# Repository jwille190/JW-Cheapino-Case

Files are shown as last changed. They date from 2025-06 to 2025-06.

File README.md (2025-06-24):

# JW-Cheapino-Case
Files for the Cheapino v2 case I designed.

__Please note that the RJ45 connector I used is 11.5mm tall.__ For the controller cover to fit, you will need that same low profile RJ45 connector.

# BOM

Printed Pieces

| Qty | Part |
| --- | --- |
|  1  | L Case body |
|  1  | R Case body (mirror in slicer) |
|  1  | L Switchplate |
|  1  | R Switchplate (mirror in slicer) |
|  1  | L Controller Cover |
|  1  | R Controller Cover (mirror in slicer)  |
|  2  | Pivot hubs |
|  2  | Magnet Circles |
|  2  | Tenting Ramps |

Hardware

| Qty  | Part |
| ---- | --- |
|  16  | M2 Heatset inserts* |
|  16  | M2 x 8mm Socket head cap screws |
| 2  | M4 Heatset inserts* |
| 2  | M4 x 10mm pan-head machine screw |
|  18  | D4x2 Round Magnet (N50M Grade from Bambu Lab Maker's Supply or similar)  |

*You can find heat set insert kits that have multiple sizes, like these. https://www.amazon.com/Threaded-Inserts-Plastic-knurled-Assortment/dp/B0DCJ4MXCM

You will need a tool to install them.

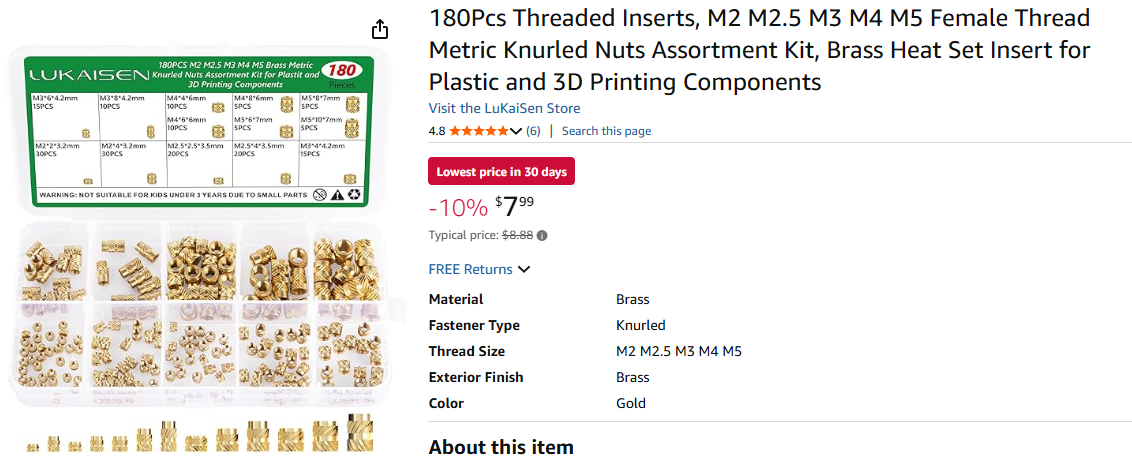
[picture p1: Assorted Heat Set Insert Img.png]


# CRITICAL ASSEMBLY NOTES:
The controller cover is specifically designed for the shorter RJ45 connector that is 11.5mm tall, check the height before assembly.
https://www.amazon.com/uxcell-Unshielded-Modular-Network-Connectors/dp/B007POCUF2
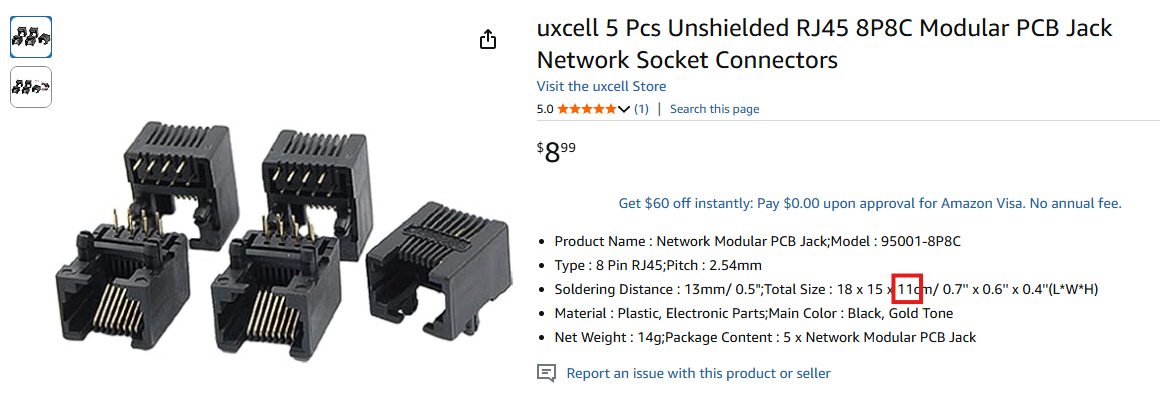
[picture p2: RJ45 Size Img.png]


It also requires short headers equal to the ones in the Adafruit short headers kit for their Feather board.
https://www.adafruit.com/product/2940f

You will need to put the controller cover in place before attaching the populated switchplate to the PCB. The cover does not have a fastener to lock it in place, just the switchplate.
Check that the USB-C connector is seated in the cutout.

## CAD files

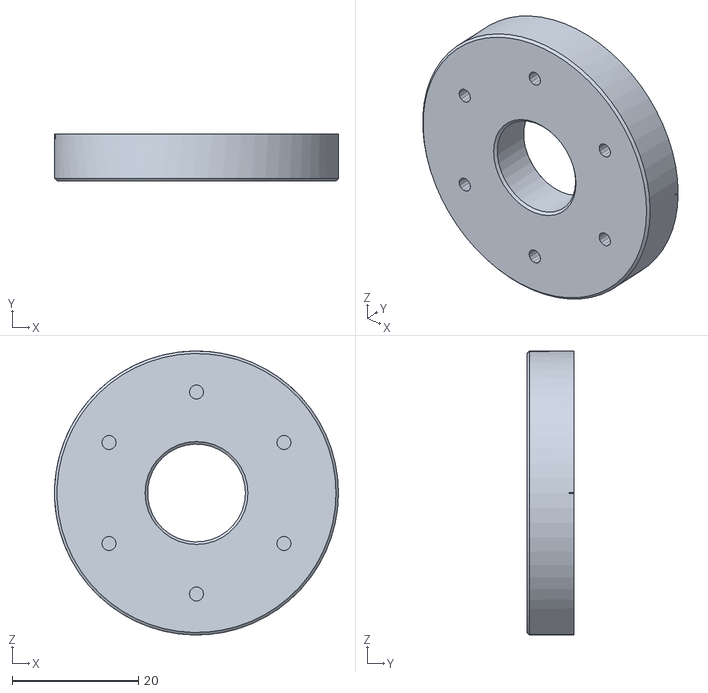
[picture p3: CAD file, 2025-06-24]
Case Ramp Magnet Circle.stl
45.0 x 7.50 x 45.0

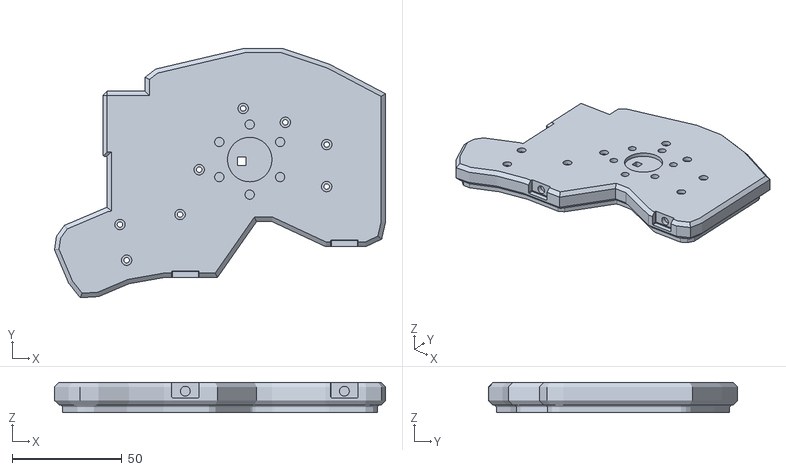
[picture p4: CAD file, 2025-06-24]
Chp_v2 Case.stl
150.9 x 113.7 x 13.8

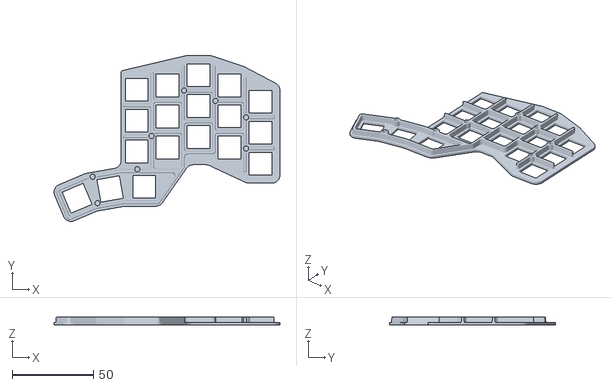
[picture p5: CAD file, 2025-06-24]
Chp_v2 Switchplate.stl
138.8 x 101.8 x 5.10

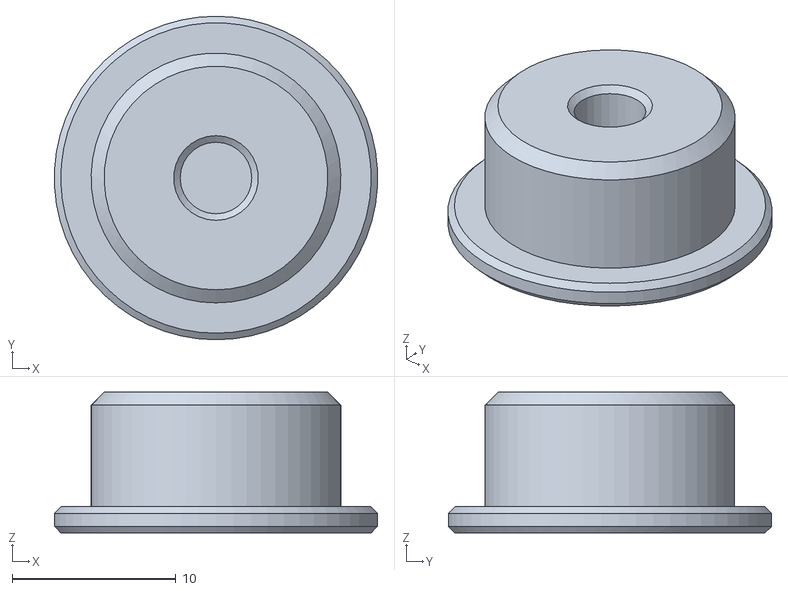
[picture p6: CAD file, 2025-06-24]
Case Ramp Pivot Hub.stl
19.7 x 19.8 x 8.60

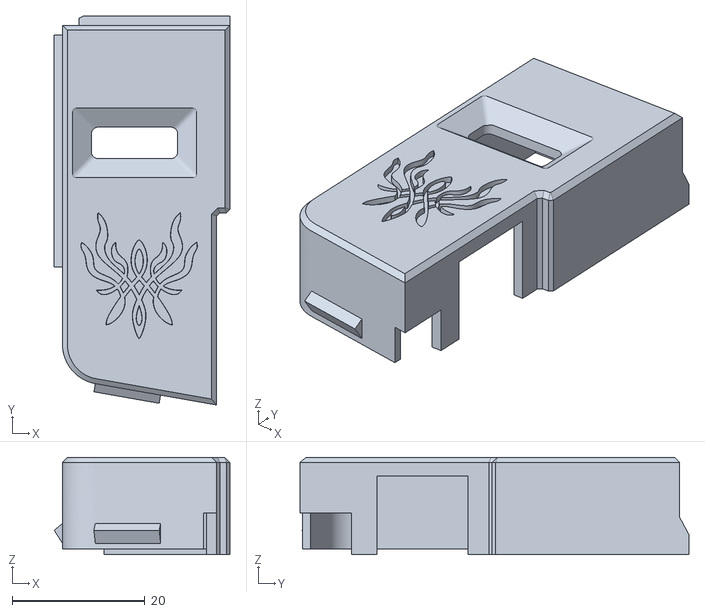
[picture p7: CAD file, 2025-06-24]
Chp_v2 Controller Cover (Crest of Flames Logo).stl
26.5 x 58.7 x 14.6

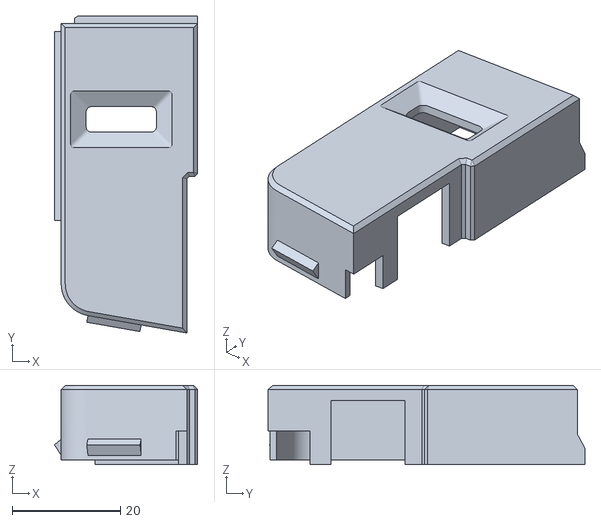
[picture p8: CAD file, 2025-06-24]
Chp_v2 Controller Cover.stl
26.5 x 58.7 x 14.6

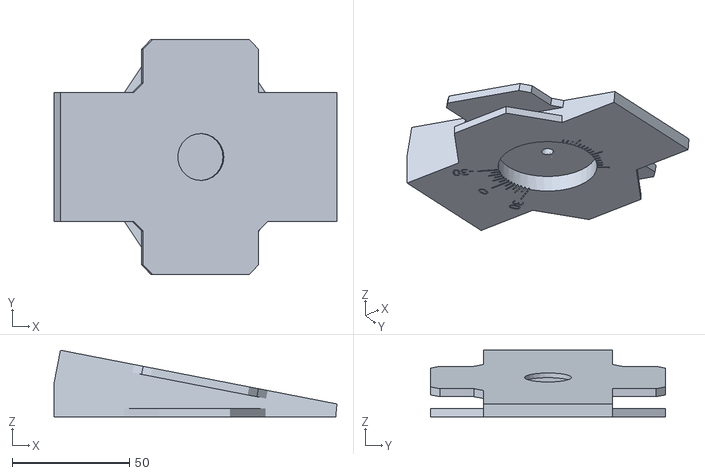
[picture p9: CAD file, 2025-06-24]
Case Tenting Ramp Solid Block.stl
120.5 x 100.0 x 28.4

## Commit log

2025-06-24 Add files via upload
    Initial publish of case STLs for the Cheapino v2 by Tompi.
    [Case Ramp Magnet Circle.stl, Case Ramp Pivot Hub.stl, Case Tenting Ramp Solid Block.stl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]
2025-06-24 Create BOM
2025-06-24 Update BOM
